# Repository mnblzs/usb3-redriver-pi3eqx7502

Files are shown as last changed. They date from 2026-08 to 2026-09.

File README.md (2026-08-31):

# USB 3.0 ReDriver 中继板（PI3EQX7502）

> 基于 PI3EQX7502 的 USB 3.0 信号中继扩展板 —— 解决长线缆下 USB 3.0 链路训练失败、降级到 USB 2.0 的问题。

**简体中文** | [English](README_EN.md)









板子尺寸 43.59 × 57.42 mm，双层板。

| 内容 | 路径 |
| --- | --- |
| 原理图 PDF / 矢量 SVG | [`hardware/schematic.pdf`](hardware/schematic.pdf) · [`schematic.svg`](hardware/schematic.svg) |
| 物料清单（带立创编号，可直接下单） | [`hardware/BOM.csv`](hardware/BOM.csv) |
| Gerber 制板文件 | [`hardware/gerber/Gerber_PCB2_4_2026-09-01.zip`](hardware/gerber/Gerber_PCB2_4_2026-09-01.zip) |
| EasyEDA 工程源文件（.epro2） | [`hardware/source/`](hardware/source) |
| 3D 模型（STEP） | [`hardware/3d/`](hardware/3d) |

## 目录

- [一、这个项目解决什么问题](#一这个项目解决什么问题)
- [二、核心规格](#二核心规格)
- [三、信号链路与方向定义](#三信号链路与方向定义)
- [四、硬件设计详解](#四硬件设计详解)
  - [4.1 ReDriver 配置电路（EQ / DE 三电平）](#41-redriver-配置电路eq--de-三电平)
  - [4.2 电源设计](#42-电源设计)
  - [4.3 AC 耦合电容](#43-ac-耦合电容)
  - [4.4 USB 2.0 通道的处理](#44-usb-20-通道的处理)
- [五、PCB 设计](#五pcb-设计)
- [六、BOM 物料表](#六bom-物料表)
- [七、接口与引脚定义](#七接口与引脚定义)
- [八、组装与焊接](#八组装与焊接)
- [九、使用说明](#九使用说明)
- [十、验证方法与实测参考](#十验证方法与实测参考)
- [十一、复刻指南](#十一复刻指南)
- [十二、开源协议](#十二开源协议)
- [十三、版本历史](#十三版本历史)
- [附录](#附录)

---

## 一、这个项目解决什么问题

在做机器人项目时遇到这种情况：Jetson Orin 装在机身内部，深度相机等 USB 3.0 外设需求要装在外壳或机械臂末端，用户接口需要通过转接线 + 接口板的方式对外输出。多次转接+外接线缆过长，5 Gbps 的 SuperSpeed 信号衰减到链路训练失败，主机自动回落到 USB 2.0 —— 设备能识别，但跑不动 USB 3.0。

> Jetson Orin 只是本项目遇到的场景。**这块板不挑主机** —— 只要主机和外设之间有一段长线缆，任何带 USB 3.0 口的主机都适用：工控机、x86 主机、其他 ARM 板都一样。下文教程里一律称"主机"。

**典型症状**：设备能被识别，`lsusb -t` 里却挂在 `480M` 而不是 `5000M` 下，相机掉帧、跑不满分辨率。

| 方案 | 优点 | 缺点 |
| --- | --- | --- |
| 有源光缆 AOC | 可靠，距离长（10~50 m） | 贵，线缆硬 |
| 光纤延长器 | 距离最长 | 最贵，两端供电 |
| **无源线缆 + ReDriver 中继板** | **便宜，线缆柔软** | 距离有限（本项目实测 3 m） |

本项目选第三种：串一颗 USB 3.0 ReDriver 在链路中间，对衰减信号做**均衡（EQ）+ 整形 + 去加重（DE）**后重新驱动输出。

> **注意**：ReDriver 只做模拟信号调理，不做协议层重定时（那是 Retimer 的活），所以它不能消除抖动累积。

> **这块板的定位**：单通道 + 8 位拨码，是用来摸索 EQ / DE 增益配置组合的**标定板**，不是最终装机形态 —— 设计取舍见 4.1 节末尾的「设计意图」。

---

## 二、核心规格

| 项目 | 参数 |
| ----- | --- |
| 主控芯片  | PI3EQX7502AIZDEX（Diodes，原 Pericom） |
| 支持速率  | USB 3.2 Gen 1 / USB 3.0，5 Gbps |
| 通道数 | 2 条独立 5 Gbps 差分对（一收一发，构成 1 个 USB 3.0 口） |
| 差分阻抗  | 100 Ω CML I/O |
| 主机侧接口 | U11 — HC-USB3.0-L257-P，USB 3.0 Type-A 母座（板边侧插） |
| 外设侧接口 | USB5 — GSB412137CHR，USB 3.1 Gen 2 Type-A 母座 9P（立式） |
| 供电 | 取自 USB VBUS（5 V），板载 AMS1117-3.3 降为 3.3 V |
| 配置方式  | 8 位拨码开关 + 4.7 kΩ 排阻，实现 EQ / DE 三电平 |
| PCB | 2 层，43.59 × 57.42 mm，1.6 mm FR-4 |
| 安装 | 2 × M3 螺丝孔，孔距 24.0 mm |
| 实测距离  | 3 m（板子 ↔ 外设） |

### ⚠️ 主芯片采购风险

**PI3EQX7502AI 已被 Diodes 标记为 NRND（不建议用于新设计）**，随时可能停产。数据手册首页直接点名了替代型号：

> 原文：*"Not Recommended for New Design, **Use PI3EQX7741AI**"*

- 新项目选型建议直接看 **PI3EQX7741AI**（需自行核对引脚兼容性，本项目未验证）；
- 复刻前确认 LCSC（C526708）库存；
- 自用 / 学习的话，7502 的库存货完全够用。

本文数据均来自官方数据手册 **DS41855 Rev 1-3（2019-04）**。

---

## 三、信号链路与方向定义

USB 3.0 在 USB 2.0 的 4 根线之外，增加了两组 SuperSpeed 差分对。命名是**相对于设备自身**的：`SSTX±` = 本端发送，`SSRX±` = 本端接收。所以 Host 的 SSTX 要接到 Device 的 SSRX（交叉）。

| 通道 | ReDriver 输入 | ReDriver 输出 | 方向 | 承载信号 |
| --- | --- | --- | --- | --- |
| **A 通道** | `RXA±`（U3 pin 8/9） | `TXA±`（U3 pin 22/23） | 外设 → 主机 | 上行，输出经 C3/C4 到 `U11.SSTX±`  |
| **B 通道** | `RXB±`（U3 pin 19/20） | `TXB±`（U3 pin 11/12） | 主机 → 外设 | 下行，输出经 C1/C2 到 `USB5.SSTX±` |

已测试链路：

```
下行  主机.SSTX± → [30cm] → U11.SSRX± → U3.RXB± →[B通道]→ U3.TXB± → C1/C2 → USB5.SSTX± → [3m 长线] → 外设.SSRX±
上行  外设.SSTX± → [3m 长线] → USB5.SSRX± → U3.RXA± →[A通道]→ U3.TXA± → C3/C4 → U11.SSTX± → [30cm] → 主机.SSRX±
```

---

## 四、硬件设计详解

### 4.1 ReDriver 配置电路（EQ / DE 三电平）

PI3EQX7502 有 4 个配置脚，都是**三电平**输入：

| 引脚 | Pin | 功能 | 电平 |
| --- | --- | --- | ----- |
| `EQ_A` / `EQ_B` | 2 / 17 | 通道 A / B 输入均衡，补偿**输入之前**的线缆损耗  | L/M/H |
| `DE_A` / `DE_B` | 3 / 16 | 通道 A / B 输出去加重，补偿**输出之后**的线缆损耗 | L/M/H |

```
前一段信道          ReDriver                 后一段信道
───[线缆]──► RX± ──[EQ 均衡]──►[驱动]──►[DE 去加重]──► TX± ───[线缆]──►
             补偿"前面"的损耗      补偿"后面"的损耗
```

**一句话记住：长线在哪一侧，就把那一侧的档位调大。**

三电平门限：`L` < 0.2 V<sub>DD</sub>、`M` 0.4~0.6 V<sub>DD</sub>、`H` > 0.8 V<sub>DD</sub>。芯片内部会把悬空脚偏置到 0.5 V<sub>DD</sub>，所以**什么都不接 = M 档**。

#### 本板的拨码实现

每个配置脚分配 SW1 的 **2 位**（一位上拉 3V3、一位下拉 GND，各串 4.7 kΩ），比焊固定电阻灵活：

| 配置脚 | 上拉位 | 下拉位 |
| --- | --- | --- |
| `EQ_A` | 位 8 | 位 7 |
| `DE_A` | 位 4 | 位 3 |
| `EQ_B` | 位 6 | 位 5 |
| `DE_B` | 位 2 | 位 1 |

档位组合：**H** = 上拉 ON / 下拉 OFF；**M** = 都 OFF；**L** = 上拉 OFF / 下拉 ON。（都 ON 会分压到 1.65 V，等效 M，但白白耗电 350 µA，不推荐。）

各档位数值（数据手册 "Mode Adjustment" 表）：

| 档位 | EQ 均衡量 | DE 去加重量 |
| --- | --- | --- |
| **L** | 3 dB | 0 dB |
| **M**（芯片默认） | **6 dB** | **−3.5 dB** |
| **H** | 9 dB | −6 dB |

注意：EQ 没有 0 dB 档，最小 3 dB；DE 的 dB 是负值，表示对输出摆幅的衰减。

#### 实测配置（已验证）

```
SW1:  [1]=ON  [2]=OFF [3]=OFF [4]=OFF [5]=OFF [6]=OFF [7]=ON  [8]=OFF
      DE_B=L          DE_A=M          EQ_B=M          EQ_A=L
       0 dB            -3.5dB           6dB             3dB
```

即**位 1、位 7 ON，其余 OFF**。这个配置与作者手上那块四路板（内部项目，暂不开源；用固定电阻 pinstrap，标注 `n'c'c` 的不贴）推出的结果完全一致 —— 两条独立路径互相印证。

> ✅ 已实测：30 cm 公转公接主机 + 3 m 公转 Micro-B 接 RealSense D450，稳定跑在 5 Gbps。

#### 💡 实测够用，但理论上有优化空间

长线在外设侧，按理说该把 `EQ_A`（补上行输入）和 `DE_B`（补下行输出）调大，可实测配置在这两处都取了最小值（3 dB / 0 dB），理论上还有 3~6 dB 空间 —— **但 3 m 照样稳**。

原因：ReDriver 的中继增益本身就够，它把输入恢复到满摆幅（典型 1000 mV）再驱动出去，这段"白赚"的增益已覆盖 3 m 损耗。EQ/DE 是锦上添花。

想压更远（4~5 m+）时，先试这个组合：

```
SW1:  [1]=OFF [2]=ON  [3]=OFF [4]=OFF [5]=OFF [6]=OFF [7]=OFF [8]=ON
      DE_B=H          DE_A=M          EQ_B=M          EQ_A=H
       -6dB            -3.5dB           6dB             9dB
```

> EQ 不是越大越好，开太大会连噪声一起放大。H 档反而变差就退回 M。

#### 另外三个配置脚 —— 悬空是正确的

| 引脚 | Pin | 内部电阻 | 悬空状态 |
| --- | --- | --- | --- |
| `EN_A#` / `EN_B#` | 10 / 21 | 200 kΩ **下拉** | 逻辑 0 → 通道使能 |
| `RxD_EN` | 5 | 200 kΩ **上拉** | 逻辑 1 → 接收检测激活 |

数据手册确认：**悬空是设计意图，不是遗漏**，正好落在配置表的最佳状态（Chip and channel enabled, receiver detect is active）。需要用 GPIO 控制低功耗时才把这些脚引出来。

芯片还有自适应功耗管理：信号检测器空闲 > 1.3 ms 进低功耗；低功耗下再空闲 > 6 ms 重启接收检测循环。设备拔掉会自动省电，无需干预。

#### 设计意图：为什么是单通道 + 拨码

这块板的定位是**增益配置标定工具**，不是最终产品形态。单通道和拨码都是为这个目的服务的。

**为什么只做一路**

作者手上另有一块四路版本（内部项目，暂不开源），那是往整机里装的。但用它来试增益配置很别扭：四路同时工作，改一次配置要动 4 套电阻，通道之间还有串扰和供电耦合，测出结果说不清是哪一路的功劳。

单通道把变量压到最少 —— 一条链路、一颗芯片、四个配置脚。这样测出的结论是干净的，固化到自己的多路版本上时心里有底。

**为什么用拨码而不是固定电阻**

那块四路板用的是固定电阻 pinstrap（原理图里标 `n'c'c` 的位号就是不贴）。这套做法定型后没问题，摸索阶段却很痛苦：**每试一组 EQ/DE 就要换一次料**，一次实验周期等于一次焊接周期，光对比几组配置就要焊一下午。

拨码把这层摩擦去掉了。4 个配置脚各占 SW1 的两位，3⁴ = 81 种组合全在板子上，不用动烙铁。实际调试最关心 `EQ_A` × `DE_B` 这一对（长线在外设侧时补偿这两处），扫完常用组合只要几分钟，配合 `lsusb -t` 看速率、配合掉帧观察，很快能摸到"够用"和"过头"的边界。

拨码能直接挂上去的前提是：配置脚是**直流电平**而非高速信号，接触电阻和那点寄生参数完全无所谓。

**代价与后续**

SW1 是 16P 封装（11.7 × 5.4 mm）外加 8 颗 4.7 kΩ，比固定电阻占面积、也贵。所以定型之后应该改回固定电阻 pinstrap，或换用 I²C 配置的 ReDriver。

> **复刻提示**：目标是"装到机器里用"的话，把本板测出的配置固化成固定电阻更合适（省掉 SW1 和 8 颗 4.7 kΩ）。需要多路时，可参照本板的单路设计自行扩展 —— 作者手上的四路版本暂不开源，无法提供设计文件。这块板的价值在于：在动手做最终版本之前，先把增益配置这块的不确定性测清楚。

---

### 4.2 电源设计

```
U11 VBUS +5V ──┬──► C19 (10µF) ──► GND              输入滤波
               └──► U1 (AMS1117-3.3S, SOT-89-3) ──► 3V3
                      ├──► C18 (22µF) ──► R12 ──► GND     阻尼
                      ├──► C5, C6 (100nF) ──► GND         去耦
                      └──► U3 pin 1 / pin 13 (Vdd33)
```

- **供电来源**：主机侧 VBUS 取 5 V，无需外接电源。注意这路和外设供电共用，USB 3.0 端口标准供电 900 mA，外设功耗大时要留余量。
- **C18 + R12 阻尼**：AMS1117 这类老架构 LDO 对输出电容 ESR 有要求（0.1~10 Ω），MLCC 的 ESR 太低会振荡。所以在 22 µF 陶瓷电容接地路径串一颗小电阻（R12）人为抬高 ESR，取值 **1 Ω**（富捷 FRC0603F1R00TS）。
- **U3 有两组 Vdd33（pin 1 和 13）**，两组都要接去耦电容。

功耗（数据手册实测值）：

| 模式 | 条件 | 典型值 | 最大值 |
| --- | --- | --- | --- |
| **Active** | 通道使能且有信号 | **328 mW** | 450 mW |
| Slumber | 通道使能，无信号 | — | 65 mW  |
| Device Unplug | 输出未端接 | 7.3 mW | — |
| Standby | `EN_x#` = 1 | 0.15 mW | 1.8 mW |

Active 电流最大 125 mA（典型 99 mA）。加上 LDO 损耗约 168 mW，板子 5 V 侧总功耗约 **496 mW**，从 VBUS 抽约 **99 mA**。SOT-89-3 热阻约 100~150 °C/W，温升 17~25 °C；装在密闭高温环境里建议给 U1 多铺铜。

---

### 4.3 AC 耦合电容

USB 3.0 规范要求 SuperSpeed 差分对串 AC 耦合电容，推荐 **100 nF**。本板 4 颗 100 nF 0402：C1/C2 在 `U3.TXB±`→`USB5.SSTX±`，C3/C4 在 `U3.TXA±`→`U11.SSTX±`。

**为什么只在 ReDriver 输出侧放？** 因为规范规定**隔直电容由发送端提供** —— Host 和 Device 送出来的信号内部已经隔直过了，而 ReDriver 自己的 CML 输出带直流偏置，必须由它自己提供。输入侧再加会和内部 50 Ω 端接形成额外高通，劣化低频响应。

布局要求：靠近 ReDriver 输出脚、0402 小封装、两颗对称摆放、正下方地平面不要挖空。

> **好消息**：数据手册明确写了输入输出引脚都 **pin polarity reversible**，差分对正负接反也能正常工作。布线绕不开时直接交叉走线即可，不用打过孔换层。

---

### 4.4 USB 2.0 通道的处理

D+ / D− 从 U11 直连到 USB5，**不经过 ReDriver**。原因：480 Mbps 衰减小，3 m 完全够用；且 USB 2.0 是半双工双向的同一对线，单向 ReDriver 没法中继。实测也印证了 —— 直连时设备能识别（只是跑 480M），说明 USB 2.0 通道从头到尾都通。

---

## 五、PCB 设计

| 项目 | 值 | 项目 | 值 |
| --- | --- | --- | --- |
| 层数 | 2（Top / Bottom） | 默认信号线宽 | 10 mil |
| 板框尺寸 | **43.59 × 57.42 mm** | 电源线宽 | 20 mil |
| 走线 / 过孔 / 焊盘 | 242 / 93 / 106 | 间距 | 5.98 mil |
| 铺铜 | 顶层 + 底层均铺 GND | 过孔 | 外径 24 / 孔径 12 mil |

安装孔（M3，接 GND，孔距 24.0 mm）：SCREW4 (16.21, 3.13 mm)、SCREW3 (40.21, 3.13 mm)，坐标相对板框左下角。

板上定义了 7 组差分对：DP45（USB2.0 D±）、DP60/DP61/DP62（B 通道）、DP63/DP64/DP65（A 通道）。其中 DP60 的极性标注反了，但芯片支持极性反转，**不影响功能**，仅为规范起见建议改正负端网络名。

**走线长度与对内等长**（仅 PCB 部分）：

| 差分对 | 正端 | 负端 | 对内偏差 |
| --- | --- | --- | --- |
| TXA± | 4.17 mm  | 4.17 mm  | **0.00 mil** |
| TXB± | 7.67 mm  | 7.64 mm  | 1.18 mil |
| RXA± | 17.20 mm | 17.23 mm | 0.84 mil |
| RXB± | 16.89 mm | 16.77 mm | 4.92 mil |
| D± (USB2.0) | 36.68 mm | 36.53 mm | 5.65 mil |

最大的 4.92 mil 换算成时间只有 0.886 ps，5 Gbps 下 1 UI = 200 ps，仅占 **0.004 UI**，可忽略。

### 阻抗控制的说明

**这块板没有做严格的 90 Ω 差分阻抗控制。** 2 层板在 1.6 mm FR-4 上做 90 Ω 差分需要约 12~15 mil 线宽配 6~8 mil 间距，本板差分线宽在 5~10 mil，实际阻抗偏高（约 100~120 Ω）。

实测仍能过是因为：板内走线很短（最长 17 mm），反射效应有限；USB 3.0 链路训练有容错；主要瓶颈在线缆不在 PCB。

追求更好性能的话：下单时向板厂明确要求"USB 3.0 差分对按 90 Ω ±10% 阻抗控制"，或直接改 4 层板。

---

## 六、BOM 物料表

整板 18 个器件（含 2 个螺丝孔），实际物料 10 种。

| 位号 | 型号 | 封装 | 数量 | 立创编号 | 说明 |
| --- | --- | --- | -- | --- | --- |
| U3 | PI3EQX7502AIZDEX | TQFN-24 (4×4, EP)  | 1  | C526708  | ReDriver，**已 NRND** |
| U11 | HC-USB3.0-L257-P | USB-3.0-A-TH | 1  | C7501847 | 主机侧 Type-A 母座 |
| USB5 | GSB412137CHR | USB-TH_9P-P2.00-V  | 1  | C464567  | 外设侧 Type-A 母座 |
| U1 | AMS1117-3.3S | SOT-89-3 | 1  | C347256  | LDO 5V→3V3 |
| SW1 | DSHP08TSGER | SW-SMD 16P (P1.27) | 1  | C3293147 | 8 位拨码开关 |
| RN1, RN2 | 4D03WGJ0472T5E | RES-ARRAY 0603-8P  | 2  | C1980 | 4.7 kΩ × 4 排阻 |
| R12 | FRC0603F1R00TS | R0603 | 1  | C2907004 | 1 Ω 阻尼电阻 |
| C1~C6 | CL05B104KO5NNNC  | C0402 | 6  | C1525 | 100 nF（4 AC 耦合 + 2 去耦） |
| C18 | CL10A226MQ8NRNC  | C0603 | 1  | C59461 | 22 µF，LDO 输出 |
| C19 | CL10A106KP8NNNC  | C0603 | 1  | C19702 | 10 µF，LDO 输入 |
| SCREW3/4 | M3 螺丝孔 | — | 2  | — | 安装孔，接 GND |

**采购提示**：

- U3 优先确认库存（NRND）。
- USB5 是 Amphenol Gen 2 规格座子，插拔寿命 5000 次但价格高（¥10~20），预算紧可换普通 USB 3.0 座（注意 9P / 2.00 mm 间距 / 通孔立式）。**换座子不会让链路跑上 10 Gbps**，瓶颈在只支持 5 Gbps 的 PI3EQX7502。
- 电容建议 X7R 或更好。注意 MLCC 直流偏压效应 —— 22 µF/6.3 V 的 0603 在 3.3 V 偏置下实际容量可能只剩一半。

---

## 七、接口与引脚定义

### U11 — 主机侧 Type-A 母座（HC-USB3.0-L257-P）

| Pin | 名称 | 板上连接 | Pin | 名称 | 板上连接 |
| --- | ----- | --- | --- | --- | --- |
| 1 | VBUS  | +5V（板子供电来源） | 7 | GND_DRAIN | GND |
| 2 | D− | 直连 USB5 pin 2 | 8 | SSTX− | ← C3 ← U3 pin 23 |
| 3 | D+ | 直连 USB5 pin 3 | 9 | SSTX+ | ← C4 ← U3 pin 22 |
| 4 | GND | GND | 10  | SHELL | GND |
| 5 | SSRX− | → U3 pin 20 | 11  | SHELL | GND |
| 6 | SSRX+ | → U3 pin 19 | | | |

### USB5 — 外设侧 Type-A 母座（GSB412137CHR）

| Pin | 名称 | 板上连接 | Pin | 名称 | 板上连接 |
| --- | ----- | --- | --- | --- | --- |
| 1 | VBUS  | +5V（给外设供电） | 6 | SSRX+ | → U3 pin 9 |
| 2 | D− | 直连 U11 pin 2 | 7 | GND_DRAIN | GND |
| 3 | D+ | 直连 U11 pin 3 | 8 | SSTX− | ← C1 ← U3 pin 11 |
| 4 | GND | GND | 9 | SSTX+ | ← C2 ← U3 pin 12 |
| 5 | SSRX− | → U3 pin 8 | 10  | SHELL | GND |

### U3 — PI3EQX7502AIZDEX（TQFN-24）

| Pin | 名称 | 板上连接 | 备注 |
| --- | --- | --- | --- |
| 1 | Vdd33 | 3V3 | 去耦 C5 |
| 2 | EQ_A | SW1 位 7/8 经 RN1 | 三电平配置 |
| 3 | DE_A | SW1 位 3/4 经 RN2 | 三电平配置 |
| 4, 6, 7 | DNC | 悬空 | Do Not Connect |
| 5 | RxD_EN | 悬空 | 内部 200 kΩ 上拉 |
| 8 / 9 | RXA− / RXA+ | USB5 pin 5 / 6 | A 通道输入（极性可反转）  |
| 10 | EN_A# | 悬空 | 内部 200 kΩ 下拉 |
| 11 / 12 | TXB− / TXB+ | → C1/C2 → USB5 pin 8/9 | B 通道输出（极性可反转）  |
| 13 | Vdd33 | 3V3 | 去耦 C6 |
| 14, 15, 18 | DNC | 悬空 | Do Not Connect |
| 16 | DE_B | SW1 位 1/2 经 RN2 | 三电平配置 |
| 17 | EQ_B | SW1 位 5/6 经 RN1 | 三电平配置 |
| 19 / 20 | RXB+ / RXB− | U11 pin 6 / 5 | B 通道输入（极性可反转）  |
| 21 | EN_B# | 悬空 | 内部 200 kΩ 下拉 |
| 22 / 23 | TXA+ / TXA− | → C4/C3 → U11 pin 9/8  | A 通道输出（极性可反转）  |
| 24 | DNC | 悬空 | Do Not Connect |
| 25 | EP 裸焊盘 | GND | **必须焊接接地**，兼散热 |

> **DNC 脚必须悬空**，不要接任何网络（包括 GND）。  
> **EP 一定要焊**：它是主要散热路径和内部地参考。建议打 4~9 个 Ø0.3 mm 过孔连到底层 GND，过孔要塞油墨或树脂塞孔，避免回流焊锡膏流失。

---

## 八、组装与焊接

**难度：中等偏上**。主要难点是 U3 的 TQFN-24（0.5 mm 间距 + 中心裸焊盘）和两个通孔 USB 座子。

推荐顺序：

1. **U3（TQFN-24）** —— 最先焊。推荐钢网 + 回流焊 / 加热台，EP 焊盘区锡膏覆盖率控制在 50~70%（太多会把芯片顶起来虚焊）。热风枪也可行，350 °C 均匀加热，EP 需单独补锡或预植锡。焊完测 pin 1/13 对 GND 不短路、对 3V3 导通。
2. **C1~C6、C18、C19、R12** —— 0402 用尖头烙铁，先给一端焊盘上锡，镊子定位后焊一端再焊另一端。
3. **RN1 / RN2（0603-8P 排阻）** —— 引脚密，建议锡膏 + 热风枪，或多锡拖焊 + 吸锡带清理。
4. **SW1（SMD 16P）** —— 间距 1.27 mm 好焊，注意缺口方向与丝印对应。
5. **U11 / USB5（通孔座子）** —— **最后焊**（会挡住周围贴片区）。先插到位确认贴紧板面，焊 1~2 个固定脚定位后再焊完；外壳接地脚多给锡，它承担屏蔽和机械固定。
6. **U1（SOT-89-3）** —— 中间散热焊盘（pin 2 延伸）要上好锡。

焊后检查：3V3 对 GND 阻抗不应接近 0 → 插 USB 测 U3 pin 1 应为 3.3 V ±5% → 通电 1 分钟摸 U3 微温正常、烫手有问题。

---

## 九、使用说明

这一节是通用的调试流程 —— 换成你自己的主机、线缆长度和外设都适用。作者的一组具体实测数据放在第十节，用来对照结果。

### 接线

本板串在主机和外设之间，两侧都是 Type-A 母座：

```
主机 ──[短线，尽量 < 0.5 m]──► U11 ──► ReDriver ──► USB5 ──[长线：你要覆盖的距离]──► 外设
```

| 接口 | 位置 | 接什么 | 线缆建议 |
| --- | ----- | --- | --- |
| **U11** | 板边侧插  | 主机 | **越短越好**，这段线本身也衰减，能省则省 |
| **USB5** | 板上立式  | 外设 | 你的目标长度 |

无需外接电源，从主机侧 VBUS 取电。

> ⚠️ **最常见的坑是主机侧那根 A公-A公线**。两个座子都是 Type-A 母座，主机侧只能用 A公-A公线，而这种线不符合 USB-IF 规范，市售产品内部接法不统一（有的没接全 SS 差分对、有的 VBUS 直连）。**接上没反应先怀疑它** —— 换一根，或两端插头对调试试。

### 确认链路速率

```bash
lsusb -t
```

看最后那个数字：**`5000M`** ✅ 链路正常 | **`480M`** ❌ 降级了。

看到 480M 按顺序排查：

1. 换主机侧那根 A公-A公线（**最常见的原因**）；
2. 量 U3 pin 1 是否为 3.3 V，确认板子已上电；
3. 把外设侧线缆缩短到 1 m 以内试，确认不是超出了距离极限；
4. 调 SW1 的 EQ / DE 档位（见下）。

### 调整 EQ / DE

拨码对照：`EQ_A` 上拉位 8 / 下拉位 7，`DE_A` 位 4 / 位 3，`EQ_B` 位 6 / 位 5，`DE_B` 位 2 / 位 1。  
档位：**H** = 上拉 ON；**M** = 都 OFF；**L** = 下拉 ON。

推荐流程：

1. **先全部拨到 OFF**（四个脚都在芯片默认的 M 档），跑一次看基线；
2. 按长线所在的一侧加档位：

| 长线位置 | 加大这两个脚 | 原因 |
| --- | --- | --- |
| **外设侧**（最常见） | `EQ_A` + `DE_B` | 补上行输入 + 下行输出 |
| **主机侧** | `EQ_B` + `DE_A` | 补下行输入 + 上行输出 |
| 两侧都长 | 四个脚都往上推 | 逐级来，别一次拉满 |

3. 症状反推：

- 链路不稳、设备掉线 → EQ 往上调（3 → 6 → 9 dB）
- 过冲 / EMI 问题 → DE 往下调（−6 → −3.5 → 0 dB）

**每次只改一个配置脚**，改完记录。拨码不需要断电（纯电平配置，实时生效），但链路会重新训练，外设会短暂断开重连。

> 怎么调都不行的话，注意 ReDriver 只做模拟调理、不做重定时 —— 抖动是累积的。超出物理极限就得换有源线缆（AOC）或光纤方案，这不是调参能解决的。

---

## 十、验证方法与实测参考

### 建议的验证顺序

别一上来就接长线。按这个顺序做，能快速定位问题出在哪一环：

1. **短线直连**（< 1 m）主机和外设 —— 先确认这两者本身能跑 5000M；
2. **长线直连**（你的目标长度）—— 复现降级，作为对照组。如果这里还是 5000M，说明这个距离本来就没问题，不需要本板；
3. **串入本板** —— 速率应回到 5000M；
4. **压力测试** —— 让外设满负载连续跑一段时间，看有没有掉线或报错：

   - 通用：`dmesg -w | grep -i usb`，看有无 reset / disconnect
   - 相机类：满分辨率满帧率连续采集，看有无掉帧（RealSense 可用 `realsense-viewer` 观察）
   - 存储类：连续读写大文件，看有无掉盘或速率骤降

5. **按需调参**（见第九节）。

> 只有第 2 步能复现出降级、第 3 步能救回来，才说明板子确实起了作用 —— 这一步对比是判断本板是否有效的唯一标准。

### 作者的实测案例

下面这组数据来自作者的一次实测，**只是其中一个样本，不代表距离上限**。你的线缆、外设、主机不同，结果会有差异。

| 项目 | 内容 |
| ----- | --- |
| 主机 | Jetson Orin（换成其他 USB 3.0 主机同样适用） |
| 主机侧线缆 | 30 cm，USB 公转公（A公-A公）→ `U11` |
| 外设侧线缆 | 3 m，USB 公转 Micro-B → `USB5` |
| 外设 | Intel RealSense Depth Module D450 深度相机 |
| 板载配置  | `EQ_A`=L(3dB)、`DE_A`=M(−3.5dB)、`EQ_B`=M(6dB)、`DE_B`=L(0dB)，即位 1、位 7 ON |

| 场景 | 结果 |
| --- | --- |
| 不加本板，3 m 线直连 | ❌ 能识别，但**降级到 USB 2.0（480 Mbps）** |
| 串入本板 | ✅ 正常跑在 **USB 3.0（5 Gbps）** |

同样一根 3 m 线，串上板子从 480M 变 5000M，带宽提升约 10 倍 —— 对深度相机就是"能不能跑满分辨率和帧率"的分界线。

**关于 D450**：立体视觉（Active IR Stereo）+ RGB，全局快门，深度最高 1280×720@30fps，FOV 86°×57°，基线 50 mm，接口 USB 3.1。双目 + RGB 同时传流，对带宽和稳定性要求高 —— 作为测试对象它偏"苛刻"，能通过的话一般外设更没问题。

### 想压更远距离

按性价比排序：

1. **先调参**（免费）：把 `EQ_A` 调到 M/H（6/9 dB）、`DE_B` 调到 M/H（−3.5/−6 dB）；
2. **换更好的线缆**：线径粗、屏蔽好、带磁环。这一步的收益常常比调参更大；
3. **级联或改用有源光缆（AOC）**：注意 ReDriver 不做重定时，级联抖动会累积，一般不超过两级。

换什么线、能压到多长，取决于你的外设和线缆质量 —— 建议按上面的验证顺序实测，别照搬数字。

---

## 十一、复刻指南

**需要准备**：PCB（2 层 43.59 × 57.42 mm）、热风枪或加热台、烙铁、万用表、放大镜。

**步骤**：

1. 确认 U3 库存（NRND，先查 C526708）；
2. 取 Gerber：`hardware/gerber/` 下的压缩包直接用它下单。按嘉立创默认工艺即可（追求信号质量就在制板说明加"USB 3.0 差分对按 90 Ω 阻抗控制"）；
3. 按第六节 BOM 备料 → 按第八节焊接 → 按第九节接线验证 → 按第十节做"直连 vs 串板"对比。

**值得改的几处**（按性价比排序）：

1. 调 EQ/DE（零成本，长线在外设侧就把 `EQ_A` 调到 6/9 dB、`DE_B` 调到 −3.5/−6 dB）；
2. `EN_x#` 引出到排针（方便 GPIO 控制低功耗、做开关对比）；
3. 3V3 电源改铺铜；
4. 改 4 层板 + 阻抗控制（成本翻倍，信号质量提升最明显）。

---

## 十二、开源协议

本项目采用 **CERN-OHL-S v2（Strongly Reciprocal）** 授权：

- ✅ 自由使用、修改、制造、销售，可商用；
- ⚠️ 修改后分发（卖成品或发文件）必须以同样协议公开修改版源文件；
- ⚠️ 保留原作者署名和协议声明；
- ❌ 按"原样"提供，不含任何担保。

完整文本：<https://ohwr.org/project/cernohl/wikis/Documents/CERN-OHL-version-2>

> 选强著佐权版的意图是让改进也能回流社区。自己用、不分发则不受限制。

---

## 十三、版本历史

| 版本 | 说明 | 开源状态 |
| --- | --- | --- |
| **单路版本（本仓库）** | 1 × PI3EQX7502 + 8 位拨码配置。工程内原名 `PI3EQX501i`（沿用早期选型，与实际贴装型号不符，已更正） | ✅ 本仓库 |
| **V0.7 四路版本** | 4 × PI3EQX7502，EQ/DE 用固定电阻 pinstrap（`n'c'c` = 不贴），另含 DP 与 RJ45。本板配置继承自此 | ❌ 暂不开源  |
| **V0.7.1 四路版本** | V0.7 的小改版 | ❌ 暂不开源  |

> 本仓库**只开源单路版本**。V0.7 / V0.7.1 四路版是同一工程下的内部项目，**暂无开源计划**；文中提到它们只是为了交代本板配置的来源和设计背景。

---

## 附录

**工程结构**（嘉立创 EDA 专业版工程 `orin接口扩展`）：

```
├── PI3EQX501i                          ← 本仓库对应的板（schematic2_4 + PCB2_4）
├── orin接口扩展V0.7（4*PI3EQX7502）        ← 内部项目，暂不开源
├── orin接口扩展V0.7.1（4*PI3EQX7502）_1    ← 内部项目，暂不开源
├── Board1 / Board1_1 / Board2_1        ← 内部项目，暂不开源
└── 4层测试                              ← 内部项目，暂不开源
```

> 除 `PI3EQX501i` 之外，上面列出的都是同一工程下的内部项目，**不在本仓库的开源范围内**。把它们列出来只是为了让拿到本仓库源文件的人了解工程全貌 —— 这些板子的设计文件无法提供，请勿据此索取。

**参考资料**：

- PI3EQX7502AI 数据手册 — Diodes，DS41855 Rev 1-3（2019-04）。本文的 EQ/DE dB 值、三电平门限、内部上下拉、功耗、引脚定义与极性反转特性均出自此手册
- CERN-OHL-S v2 协议文本
- USB 3.2 规范（USB-IF，SuperSpeed 差分对与 AC 耦合要求）

**反馈**：设计上肯定有疏漏，欢迎反馈。

---

*最后更新：2026-09-01*

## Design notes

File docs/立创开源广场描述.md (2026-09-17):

# 立创开源广场 · 项目描述文本

> 直接复制下面的内容粘贴到项目描述编辑框。

---

## USB 3.0 信号整形器（测试用 · PI3EQX7502）

**一句话**：一块串在 USB 3.0 链路中间、带 8 位拨码的信号整形测试板 —— 81 种 EQ / DE 增益组合随手切换，用来把"长线下 SuperSpeed 掉速"这件事测清楚。

### 这是什么

这是一块**测试用的板子**，不是一个准备装进机器里长期跑的成品。

它串在主机和外设之间，用 PI3EQX7502 对衰减的 5 Gbps 信号做**均衡（EQ）+ 整形 + 去加重（DE）**后重新驱动出去，相当于给信号"续一程"。再配合 8 位拨码 —— 4 个配置脚 × 三电平 = 3⁴ = **81 种增益组合全在板子上**，不用动烙铁，可根据实际工况快速调试。

此前另开发过一块四路版本（带 DP 与网口），是往整机里装的，但发现调试增益很困难：四路同时工作，改一次配置要动 4 套电阻，通道之间还有串扰和供电耦合，测出的结果说不清是哪一路的功劳。**可优先通过该板进行增益调试，调稳后再固化到多路版。**

> ⚠️ 整形 ≠ 重定时。PI3EQX7502 只做模拟信号调理，**不做协议层重定时（那是 Retimer 的活）**，抖动会累积。这不是调参能绕过的物理限制。

### 它能用来测什么

**① 测链路 —— 判断长线到底是不是元凶**

同样是"设备能识别但跑不动"，原因可能是线缆、可能是座子、可能是主机口。这块板提供了一个干净的对照实验：长线直连跑一次（复现降级）→ 串入本板跑一次（速率回来）→ 结论就出来了。只有这两步都做到，才能说问题确实出在信号衰减上。

**② 测增益 —— 找出"够用"和"过头"的边界**

拨码的意义就在这儿。改一组配置 = 拨一下开关，不用换料不用焊，配合 `lsusb -t` 看速率、配合压力测试看掉线，很快能摸到边界在哪。EQ 开太大会连噪声一起放大，H 档反而变差就退回 M —— 这种"试出来"的经验，靠看数据手册是得不到的。

**③ 测线缆和外设 —— 反过来用它当基准**

板子状态已知、可复现，减少整机变量：同一套配置下换几根线，哪根线材好、哪根差，一眼能看出差别。作者的体会是，**换线这一步的收益常常比调参更大**。

### 实测参考

作者的一组数据（只是其中一个样本，不代表距离上限 —— 线缆、外设、主机不同，结果会有差异）：

```
Jetson Orin ──30cm 公转公(A公-A公)──► U11 ──► ReDriver ──► USB5 ──3m 公转 Micro-B──► RealSense D450
位 1、位 7 ON → EQ_A=L(3dB)、DE_A=M(−3.5dB)、EQ_B=M(6dB)、DE_B=L(0dB)
```

| 场景 | 结果 |
| --- | --- |
| 不加本板，3 m 线直连 | ❌ 能识别，但**降级到 USB 2.0（480 Mbps）** |
| 串入本板 | ✅ 正常跑在 **USB 3.0（5 Gbps）** |

> Orin 只是作者遇到的场景。**这块板不挑主机** —— 只要主机和外设之间有一段长线缆，工控机、x86 主机、其他 ARM 板都一样适用。

---

### 硬件速览

| 位号 | 器件 | 说明 |
| --- | --- | --- |
| U3 | PI3EQX7502AIZDEX | USB 3.2 Gen1 5 Gbps 双通道 ReDriver，TQFN-24 |
| U11 | HC-USB3.0-L257-P | 主机侧 USB 3.0 Type-A 母座（板边侧插） |
| USB5 | GSB412137CHR | 外设侧 USB 3.1 Type-A 母座（立式，Amphenol） |
| U1 | AMS1117-3.3S | LDO，VBUS 5V 降 3.3V |
| SW1 | DSHP08TSGER | 8 位拨码开关，配置 EQ / DE 三电平 |
| RN1/RN2 | 4D03WGJ0472T5E | 4.7kΩ × 4 排阻，配置脚上下拉 |
| C1~C4 | 100nF 0402 | SuperSpeed 差分对 AC 耦合电容 |

2 层板，43.59 × 57.42 mm，2 个 M3 安装孔（孔距 24.0 mm），从主机侧 VBUS 取电，无需外接电源。

**信号链路**：A 通道跑上行（外设→主机），B 通道跑下行（主机→外设）；USB 2.0 的 D± 直连、不进 ReDriver（480 Mbps 衰减本来就小，且是半双工同一对线，单向整形器没法中继）。两个座子都是 Type-A 母座 —— 这块板是**串在链路中间**的，不是终端接口。

> AC 耦合电容只在 ReDriver **输出侧**：规范要求隔直电容由发送端提供，Host 和 Device 送出的信号内部已经隔直过了，而 ReDriver 的 CML 输出自带直流偏置，必须自己提供。

---

### EQ / DE 拨码配置

`EQ_A`/`DE_A`/`EQ_B`/`DE_B` 四个三电平脚，用 SW1 拨码切换（上拉 ON = **H**，都 OFF = **M**，下拉 ON = **L**）：

| 配置脚 | 上拉位 | 下拉位 |
| --- | --- | --- |
| `EQ_A` | 位 8 | 位 7 |
| `DE_A` | 位 4 | 位 3 |
| `EQ_B` | 位 6 | 位 5 |
| `DE_B` | 位 2 | 位 1 |

| 档位 | EQ 均衡量 | DE 去加重量 |
| --- | --- | --- |
| **L** | 3 dB | 0 dB |
| **M**（芯片默认） | 6 dB | −3.5 dB |
| **H** | 9 dB | −6 dB |

**EQ 补偿输入之前的线缆，DE 补偿输出之后的线缆** —— 长线在哪一侧，就加大那一侧。

**扫描建议**（每次只改一个配置脚，改完记录）：

1. 全部拨到 OFF（四个脚都在芯片默认 M 档），跑一次拿基线；
2. 长线在外设侧就加大 `EQ_A` + `DE_B`，在主机侧就加大 `EQ_B` + `DE_A`，两侧都长就逐级往上推，别一次拉满；
3. 链路不稳 / 掉线 → EQ 往上调（3 → 6 → 9 dB）；过冲 / EMI → DE 往下调（−6 → −3.5 → 0 dB）。

拨码不需要断电（纯电平配置，实时生效），但链路会重新训练，外设会短暂断开重连。

- **作者的实测配置**（3 m 内可直接抄）：位 1、位 7 ON，其余 OFF
- **想压更远（4~5 m+）**：位 2、位 8 ON，其余 OFF → `EQ_A`=H(9dB)、`DE_B`=H(−6dB)

---

### 怎么用

```
主机 ──[短线，尽量 < 0.5 m]──► U11 ──► ReDriver ──► USB5 ──[长线：需要覆盖的距离]──► 外设
```

1. **U11** 用短线接主机 —— 越短越好，这段线本身也会衰减；
2. **USB5** 接长线和外设；
3. 板子从主机侧 VBUS 取电，无需外接电源。

```bash
lsusb -t    # 5000M ✅ 正常 | 480M ❌ 降级
```

**别一上来就接长线**，按这个顺序能快速定位问题出在哪一环：

1. 短线直连（< 1 m）—— 先确认主机和外设本身能跑 5000M；
2. 长线直连 —— 复现降级，作为对照组（**如果这里还是 5000M，说明这个距离本来就没问题，不需要本板**）；
3. 串入本板 —— 速率应回到 5000M；
4. 压力测试 —— `dmesg -w | grep -i usb` 看有无 reset / disconnect；相机类满分辨率满帧率连续采集看掉帧；
5. 按需调参。

**看到 480M 的排查顺序**：

1. **先换主机侧那根 A公-A公线** —— 两侧都是母座，主机侧只能用 A公-A公，这种线不符合 USB-IF 规范、市售接法不统一，**是最常见的坑**；
2. 测 U3 pin 1 是否为 3.3V，确认上电；
3. 把外设侧线缆缩短到 1 m 内试，确认不是超出距离极限；
4. 按长线所在侧调档。

---

### ⚠️ 复刻前请注意

1. **PI3EQX7502AI 已 NRND**（不建议新设计用），官方点名替代型号 **PI3EQX7741AI**（引脚兼容性需自行核对，本项目未验证）。下单前查立创 C526708 库存。
2. **焊接难度中等偏上**：TQFN-24（0.5mm 间距 + 中心裸焊盘）+ 0402 + 两个通孔 USB 座。建议开钢网 + 热风枪/加热台，**EP 裸焊盘必须焊接接地**（它是主要散热路径和内部地参考）。
3. **这块板没做严格 90 Ω 阻抗控制**（2 层板 1.6 mm FR-4 上做 90 Ω 需约 12~15 mil 线宽，本板 5~10 mil，实际约 100~120 Ω）。实测仍能过是因为板内走线很短（最长 17 mm），主要瓶颈在线缆不在 PCB。追求性能就下单时要求"USB 3.0 差分对按 90 Ω ±10% 阻抗控制"，或改 4 层板。

> 已修复：底层丝印未镜像（52 处）+ 位号朝向不正（13 处），`silkFlipped` 55→0、ERROR 52→0。

> **复刻提示**：目标是"装到机器里用"的话，把本板测出的配置固化成固定电阻更合适（省掉 SW1 和 8 颗 4.7 kΩ）。这块板的价值在于 —— 在动手做最终版本之前，先把增益配置这块的不确定性测清楚。

---

### 开源协议

**CERN-OHL-S v2**（强著佐权）：可自由使用、修改、商用；修改后分发的版本须以同样协议开源。

完整技术文档（BOM、引脚定义、走线分析、焊接顺序、EQ / DE 设计意图）见附件 `README.md`。

欢迎反馈：不同线缆/外设组合下实测出的最优 EQ/DE 档位、成功替换的在产型号、改 4 层板后的对比。

---

*最后更新：2026-09-18*  
*技术数据依据：Diodes PI3EQX7502AI 数据手册 DS41855 Rev 1-3*

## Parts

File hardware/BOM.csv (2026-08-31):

No. | Quantity | Comment | Designator | Footprint | Value | Manufacturer Part | Manufacturer | Supplier Part | Supplier
1 | 6 | 100nF | C1,C2,C3,C4,C5,C6 | C0402 | 100nF | CL05B104KO5NNNC | SAMSUNG(三星) | C1525 | LCSC
2 | 1 | 22uF | C18 | C0603 | 22uF | CL10A226MQ8NRNC | SAMSUNG(三星) | C59461 | LCSC
3 | 1 | 10uF | C19 | C0603 | 10uF | CL10A106KP8NNNC | SAMSUNG(三星) | C19702 | LCSC
4 | 1 | 1Ω | R12 | R0603 | 1Ω | FRC0603F1R00TS | FOJAN(富捷) | C2907004 | LCSC
5 | 2 | 4.7kΩ | RN1,RN2 | RES-ARRAY-SMD_0603-8P-L3.2-W1.6-BL | 4.7kΩ | 4D03WGJ0472T5E | UNI-ROYAL(厚声) | C1980 | LCSC
6 | 2 | M3螺丝 | SCREW3,SCREW4 | M3螺丝
7 | 1 | DSHP08TSGER | SW1 | SW-SMD_16P-L11.7-W5.4-P1.27-LS8.5 |  | DSHP08TSGER | 康深 | C3293147 | LCSC
8 | 1 | AMS1117-3.3S | U1 | SOT-89-3_L4.5-W2.5-P1.50-LS4.2-BR |  | AMS1117-3.3S | UMW(友台半导体) | C347256 | LCSC
9 | 1 | PI3EQX7502AIZDEX | U3 | TQFN-24_L4.0-W4.0-P0.50-BL-EP2.6 |  | PI3EQX7502AIZDEX | DIODES(美台) | C526708 | LCSC
10 | 1 | host | U11 | USB-3.0-A-TH_HOOYA_USB-303L-L-SU |  | HC-USB3.0-L257-P | HC(虹成电子) | C7501847 | LCSC
11 | 1 | GSB412137CHR | USB5 | USB-TH_9P-P2.00-V_GSB412137CHR |  | GSB412137CHR | Amphenol | C464567 | LCSC

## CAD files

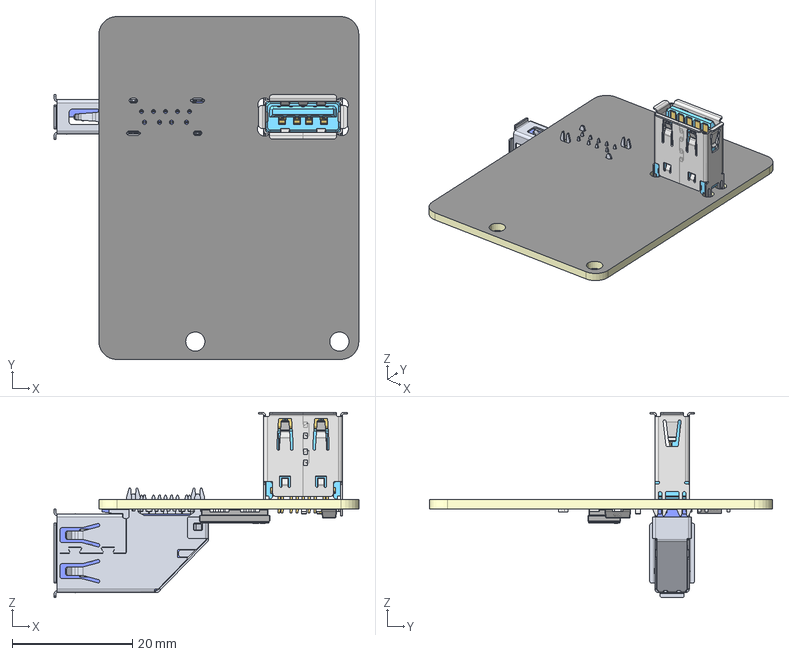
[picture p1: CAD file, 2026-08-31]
hardware/3d/3D_PCB2_4_2026-09-01.step
50.8 x 57.1 x 30.9 mm
Board~QY81
TopCopper~QY81
BottomCopper~QY81
TopSilkscreen~QY81
BottomSilkscreen~QY81
TopFpcStiffener~QY81
BottomFpcStiffener~QY81
SOT-89-3_L4.5-W2.5-P1.50-LS4.2-BR~SOT-89-3_L4.3-W2.5-H1.6-LS4.1-P1.50~KlEO
C0402~C0402_L1.0-W0.5-H0.5~YRGM x 6
C0603~C0603_L1.6-W0.8-H0.8~MgAu x 2
RES-ARRAY-SMD_0603-8P-L3.2-W1.6-BL~R0603-8P_L3.2-W1.6-H0.6~vkPA x 2
TQFN-24_L4.0-W4.0-P0.50-BL-EP2.6~TQFN-24_L4.0-W4.0-P0.50-BL-EP2.6~R0Uq
R0603~R0603~kD0I
USB-3.0-A-TH_HOOYA_USB-303L-L-SU~USB-3.0-A-TH_HOOYA_USB-303L-L-SU~J6P7
SW-SMD_16P-L11.7-W5.4-P1.27-LS8.5~SW-SMD_16P-L11.7-W5.4-P1.27-LS8.5~8R6t
USB-TH_9P-P2.00-V_GSB412137CHR~USB-TH_9P-L14.8-W7.4-H14.4~qELO

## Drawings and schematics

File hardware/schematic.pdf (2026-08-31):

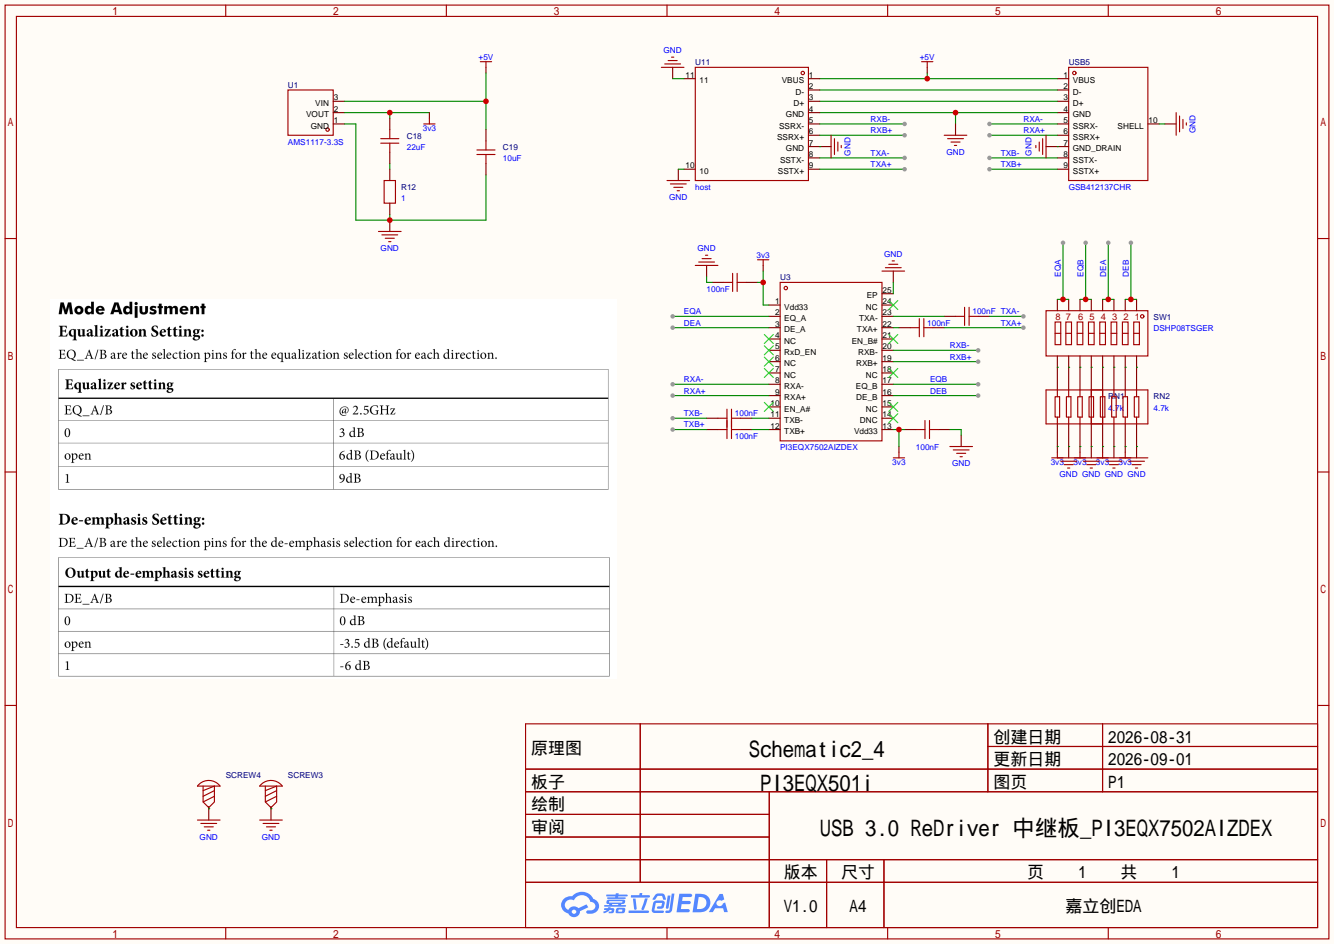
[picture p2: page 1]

原理图 | Schematic2_4 | 创建日期 | 2026-08-31
板子 | PI3EQX501i | 图页 | P1
绘制 | | USB 3.0 ReDriver 中继板_PI3EQX7502AIZDEX
审阅

更新日期 | 2026-09-01

V1.0 | A4 | 嘉立创EDA

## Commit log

2026-08-31 docs: USB 3.0 ReDriver 中继板（PI3EQX7502）开源发布
    Jetson Orin 平台的 USB 3.0 信号中继扩展板，解决长线缆下 SuperSpeed
    链路训练失败、降级到 USB 2.0 的问题。3 m 线缆实测由 480 Mbps 恢复到
    稳定 5 Gbps。
    - README：14 章完整技术文档（信号链路、EQ/DE 三电平配置、电源与 AC
    耦合设计、BOM、引脚定义、焊接顺序、实测结果、已知问题、复刻指南）
    - hardware：原理图 PDF/SVG、带立创编号的 BOM
    - images：PCB 顶层/底层渲染图
    - docs：立创开源广场描述文本
    - 协议：CERN-OHL-S v2
    [BOM.csv]
2026-08-31 docs: 统一问题背景表述，修正立创描述文本瑕疵
    - README 与立创描述同步：补充「转接线 + 接口板对外输出」这一链路变长的根因
    - 立创描述：修正「让 整机」多余空格、补全 USB 3.0 后的停顿、统一 usb3.0 大小写
2026-08-31 feat: 补全生产文件（Gerber / 源文件 / 3D），修正 R12 料号
    - 新增 Gerber 制板压缩包，可直接下单打板
    - 新增 EasyEDA 工程源文件 .epro2 与 3D 模型 STEP
    - 新增 3D 渲染图，首屏改为文件清单表格
    - R12 确定为 1 Ω（富捷 FRC0603F1R00TS / 立创 C2907004），移除待确认标注与已知问题 E-4
    - 同步 BOM.csv 与最新原理图 PDF
    [3D_PCB2_4_2026-09-01.step, BOM.csv]
2026-08-31 chore: 移除 images 目录
    同步删除首屏 PCB 配图（顶/底/3D）的引用，避免出现裂图
2026-08-31 docs: 表格对齐，修复 HTML 实体转义
2026-08-31 docs: 补充单通道 + 拨码的设计意图说明
    - 4.1 节新增「设计意图：为什么是单通道 + 拨码」：标定板定位、固定电阻
    pinstrap 的调试痛点、拨码带来的组合覆盖能力与代价
    - 首屏问题章节补充本板定位，并跳转到 4.1 设计意图
    - 同步本轮修改：副标题去掉平台限定、删除下单提示、第一节措辞细化
    - 修复第三次出现的 HTML 实体转义
2026-08-31 docs: 标注 V0.7 四路版暂不开源，同步用户删减
    - 版本历史增加「开源状态」列，V0.7 / V0.7.1 标为暂不开源
    - 移除指向 V0.7 的复刻建议，改为「参照本板单路设计自行扩展」
    - 附录工程结构逐条标注内部项目不在开源范围
    - 全文 V0.7 提及统一改为「作者手上的四路板（内部项目，暂不开源）」
    - 立创描述同步，最后更新日期改为 2026-09-01
    - 同步用户删减：第一节去「经常」、删除接口座子说明段、链路标题改「已测试链路」
    - 修复 HTML 实体转义；移除会被编辑器清理的 HTML 锚点，改为纯文本引用
2026-08-31 docs: 教程中的 Jetson Orin 改为「主机」，强调不限平台
    - 链路图、接线图、接线步骤、实测说明统一改为「主机」
    - 实测环境表改为「任意带 USB 3.0 Type-A 的主机（实测用 Jetson Orin）」
    - 背景段补充声明：这块板不挑主机，工控机/x86/其他 ARM 板均适用
    - 全文「host 侧」统一为「主机侧」
    - 立创描述同步；GitHub 仓库描述去掉「Jetson Orin 平台的」
2026-08-31 docs: 使用说明改为通用调试流程，实测数据降级为参考案例
    第九节（原「我怎么测的」视角）重写为面向任何用户的流程：
    - 接线：改为「短线接主机 + 长线接外设」的接口表，去掉具体长度/型号
    - 排查顺序：换线 → 量 3.3V → 缩短线缆 → 调档，加重最常见的 A公-A公 坑
    - 调参：从全部 OFF 起测基线，按长线所在侧查表加档，补症状反推
    第十节改名为「验证方法与实测参考」，通用验证顺序前置：
    - 短线直连 → 长线直连复现降级 → 串板 → 压力测试 → 调参
    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
2026-08-31 docs: 删除「已知问题与改进建议」章节
    移除整节内容：设计/电气（E-1~E-7）、PCB/制板（P-2~P-7）、
    原理图（S-1~S-4）、功能改进方向、底层丝印修复附记。
    后续章节重新编号并同步目录锚点：
    十二、复刻指南 → 十一
    十三、开源协议 → 十二
    十四、版本历史 → 十三
2026-08-31 docs: 全面校对后的三处修正
    - 目录补「附录」条目：此前目录 13 条 vs 正文 14 个章节，不一致
    - 修复 6 处波浪号误用：范围符号写成 ~~ 会被 Markdown 当成删除线
    渲染（12~~15 mil / 100~~120 Ω 等），改为单个 ~
    - 修正语病：4.2 节「两组 Vdd33 都要去耦到」→「都要接去耦电容」
2026-08-31 docs: 统一中英文混排空格
    副标题「基于PI3EQX7502的USB 3.0」→「基于 PI3EQX7502 的 USB 3.0」。
    全文扫描确认其余部分本就符合规范；残留的「A公」是连接器术语，按惯例连写不加空格。
2026-08-31 docs: 立创描述同步 README 的口径调整
    - 修复接线图自相矛盾：前半份是作者的实测接线，后半份是通用画法，
    现明确标注前者为「作者的实测接线，你不必照搬」
    - 补充「不挑主机」声明：Orin 只是作者遇到的场景
    - 补充标定板定位：单通道 + 8 位拨码是为摸索 EQ/DE 增益配置
    - 实测配置改称「作者的实测配置」并注明适用边界，与 README 把实测
    降级为参考案例的口径对齐
    - 文末技术文档说明去掉已删除的「改进建议」
2026-08-31 docs: 精简「复刻前请注意」为两条硬信息
    只保留真正影响复刻决策的两条：
    ① 芯片 NRND 采购风险（替代型号 PI3EQX7741AI）
    ② 焊接难度与工艺要求（TQFN-24 + 0402 + EP 裸焊盘）
    移除的四条属设计说明，README 中各有详细章节，
    docs 作为精简版指向 README 即可：
    EQ/DE 非最优 → 4.1；阻抗控制 → 第五节；
    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
2026-08-31 docs: 接线步骤移除上电测量
    接线部分只保留纯接线动作。「量 U3 pin 1 应为 3.3V」属排查动作，
    两份文档均已保留在排查顺序第 2 步（README 另在第八节焊后检查中也有），
    信息不丢失。README 与 docs 同步修改
2026-08-31 docs: 移除立创描述中的已知问题清单
    删除 6 条设计缺陷罗列（电源网络未铺铜、8 处焊盘上走线、5 处盘中孔、
    38 处 3W 间距不足、10 处丝印压焊盘、原理图 20 条零长度导线）。
    保留「已修复」的丝印记录 —— 它是正面信息，说明板子处于维护状态，
    且能让复刻者确认拿到的就是修好后的版本。
    README 的对应章节此前已删除，两份文档口径现已一致
2026-08-31 docs: 新增英文版 README
    翻译 README.md 为 README_EN.md，13 个章节全译，结构一一对应。
    - 术语按行业惯例处理：A公→A-male、排阻→resistor array、铺铜→copper pour、
    盘中孔→via-in-pad、裸焊盘→exposed pad、标定板→characterization board
    - 所有数值、型号、引脚号、立创编号原样保留，不做单位换算
    - 徽章改为英文，已验证 shields.io 渲染正确（& 转义为 %26）
    - 中英两份顶部互加语言切换链接
    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
2026-08-31 docs: 校对英文版 README，修正 6 处表达
    逐段校读后的问题：
    - 'the board derives' 主语是板子，拟人化 → 'the configuration arrived at on...'
    - 'spec'd' 缩写偏口语 → 'specified'
    - 'give U1 extra copper' 直译 → 'add extra copper pour around U1'
    - 'Only when...have you shown' 倒装绕口 → 改为直陈
    - 'the difference between hitting...or not' 结构不完整 → 补全
    - 'keep what you can' 把中文「能省则省」的意思译反了 → 'cut it down as much as you can'
    附录工程名保留中文原名并加英文译注（4层测试 → 4-layer test board），
    并说明不改名的原因：需与 EDA 工程内的实际名称对应，否则找不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
2026-08-31 docs: 最终校对，统一数值精度
    板子尺寸在同一项目内有两种写法（43.59 × 57.42 与 43.6 × 57.4），
    统一为精确值，涉及中文复刻指南、英文复刻指南、立创描述硬件段。
    孔距 24 mm 也统一为 24.0 mm，与 README 的设计值一致。
    校对范围：三份文档 + BOM.csv + GitHub 元数据。
    结论：BOM 11 项料号三向一致；功耗自洽（328+168=496 mW，5V 侧 99 mA）；
    中英文结构 1:1；锚点、链接、代码块、格式全部通过
2026-09-17 docs: 立创开源广场描述改版为「测试用 USB 3.0 信号整形器」定位
    - 定位从「解决长线问题的中继板」调整为「用于测试的信号整形器」
    - 新增「它能用来测什么」：测链路、测增益、测线缆外设三种测试用法
    - 补充扫描建议、分步验证顺序、对照实验的必要性
    - 补充阻抗控制未做的说明与 ReDriver 不做重定时的限制
    - 更新日期至 2026-09-18
2026-09-17 docs: 减少描述文本中的第二人称
    - 去掉正文中的「你/你的」，改为中性表述（多路版本、线缆外设、目标长度等）
    - 操作步骤保留祈使句式，去掉称呼性代词
2026-09-17 docs: 精简「这是什么」一节措辞
    - 拨码描述改为「可根据实际工况快速调试」，去掉与后文重复的表述
    - 四路版本改为客观叙述（此前另开发过），点明用途
    - 结论改为「可优先通过该板进行增益调试，调稳后再固化到多路版」
2026-09-17 docs: 删除描述文本中的图片占位符
    - 移除 3 处「【插入图片：xxx】」占位行
    - 顶部说明同步去掉占位符说明，改为可直接复制粘贴
2026-09-17 docs: 删除实测参考中关于深度相机的总结句
2026-09-17 docs: 「测线缆和外设」收尾改为「减少整机变量」
